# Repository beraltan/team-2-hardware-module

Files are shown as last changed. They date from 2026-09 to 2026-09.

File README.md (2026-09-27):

# Team 2 · Cardboard Camera

The battery is optional; the module can run on USB power. The outer shell is up to your group—get creative with its shape, materials and decoration!

## Assembly

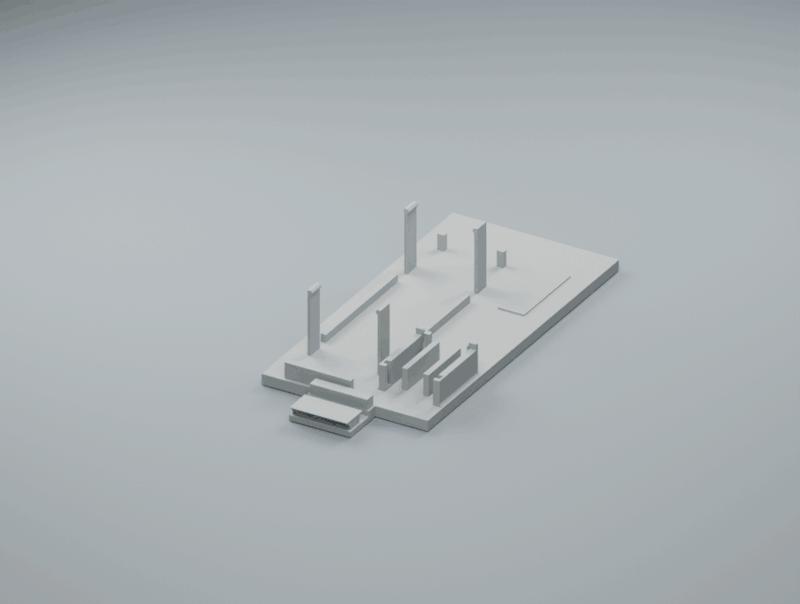
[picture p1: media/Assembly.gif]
Assembly video


[Watch / download video](media/Assembly.mp4)

## Print files

[Sled](design/cardboard-camera/Electronics%20Sled.stl) · [ESP lock](design/cardboard-camera/ESP%20Lock.stl) · [Radar holder](design/cardboard-camera/Radar%20Holder.stl) · [Front cover](design/cardboard-camera/Front%20Cover.stl)

[Assembly & wiring instructions](docs/BUILD_GUIDE.md)

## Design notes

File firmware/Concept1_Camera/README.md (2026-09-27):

# Radar camera firmware

Open Concept1_Camera.ino with both headers in this folder. Board: Seeed Studio XIAO ESP32-C3. Tested toolchain: Espressif Arduino core 3.3.11, ArduinoJson 6.21.5. Enable USB CDC on boot. CLI FQBN: esp32:esp32:XIAO_ESP32C3:CDCOnBoot=default.

The firmware reads LD2450 UART at 256000 8N1 and outputs USB JSON at 5 Hz. Wi-Fi credentials are entered through the local setup portal and stored on the device, not in source. The protected setup AP is named Team2-Camera-<device suffix>; obtain its generated password through the software facilitator's authenticated setup-info action over USB. Join the AP, then open http://192.168.4.1. OOCSI remains a separate opt-in setting.

Current directional LED firmware compiled successfully but still needs flashing and optical testing on the assembled device. Earlier versions were tested on USB/Wi-Fi; this does not verify the current guidance patterns. The LD2450_USB_Test sketch is a minimal diagnostic alternative.

See the repository README for wiring, build instructions and the paired software module.

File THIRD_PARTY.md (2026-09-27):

# Sources and rights

LD2450 manual: https://www.tinytronics.nl/product_files/006000_HLK-LD2450-Instruction-Manual.pdf

XIAO documentation: https://wiki.seeedstudio.com/XIAO_ESP32C3_Getting_Started/

Arduino-ESP32 and ArduinoJson are external dependencies, not bundled. OOCSI protocol implementation follows the official iddi/oocsi-python client. The included CAD is the Team 2 prototype with component clearance envelopes; these are not manufacturer-certified exact component models. No project-wide licence has been chosen by the team yet.

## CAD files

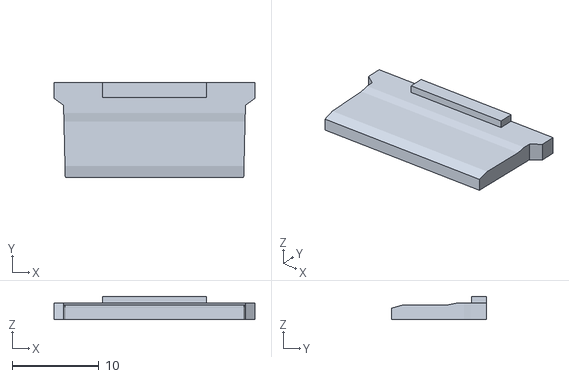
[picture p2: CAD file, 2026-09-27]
design/cardboard-camera/ESP Lock.stl
23.2 x 10.9 x 2.70

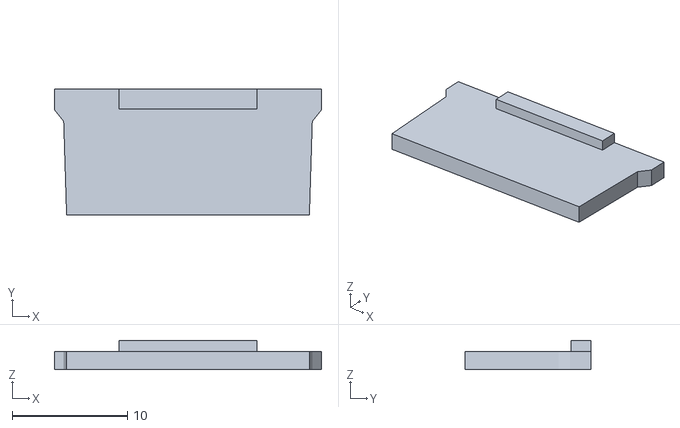
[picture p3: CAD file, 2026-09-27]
design/fit-checks/ESP End Stop Fit.stl
23.2 x 10.9 x 2.55

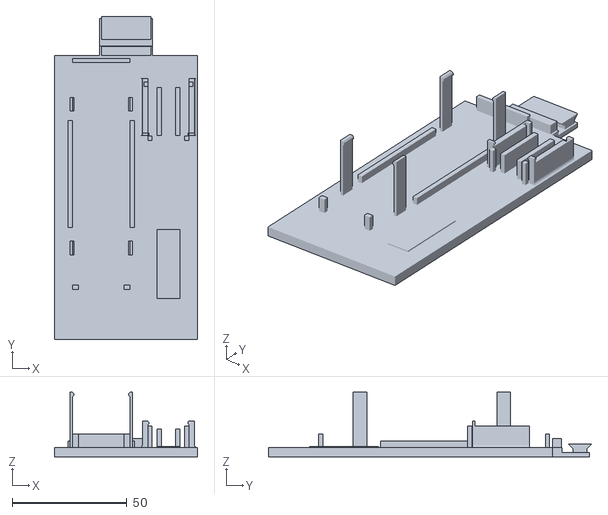
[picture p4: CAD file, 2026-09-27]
design/cardboard-camera/Electronics Sled.stl
62.4 x 141.0 x 28.2

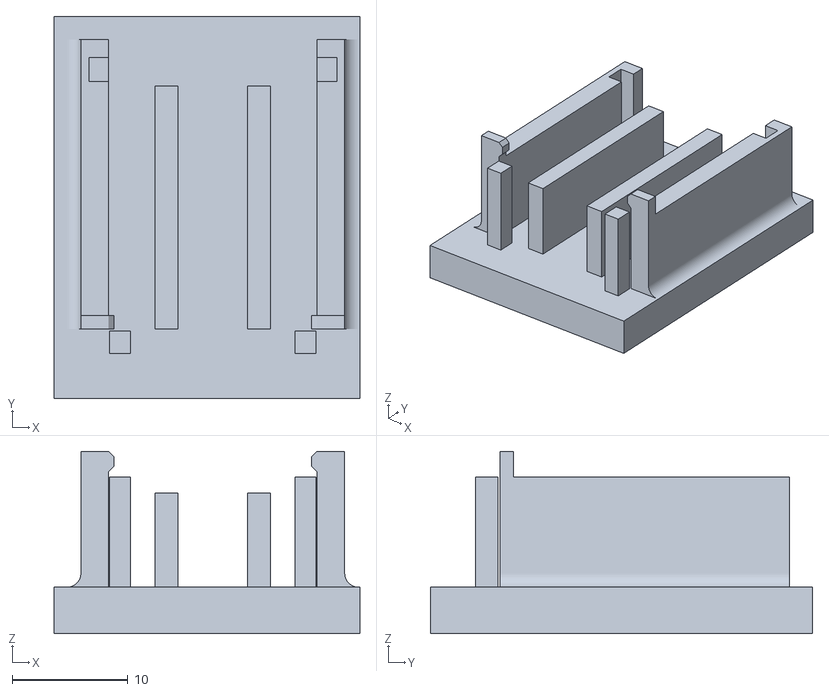
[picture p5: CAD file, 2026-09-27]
design/fit-checks/ESP Holder Fit Test.stl
26.4 x 33.0 x 15.7

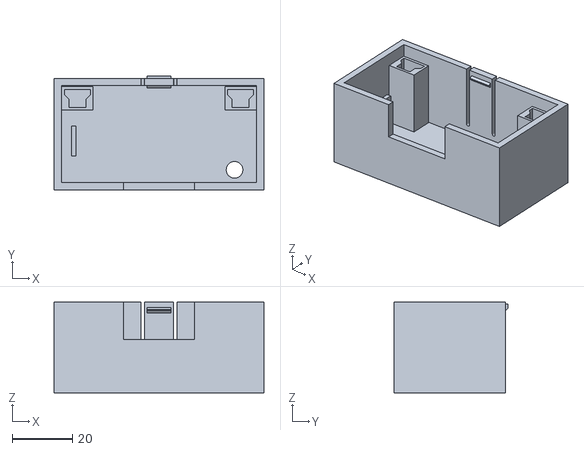
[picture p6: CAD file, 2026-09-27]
design/cardboard-camera/Front Cover.stl
69.5 x 37.6 x 30.0

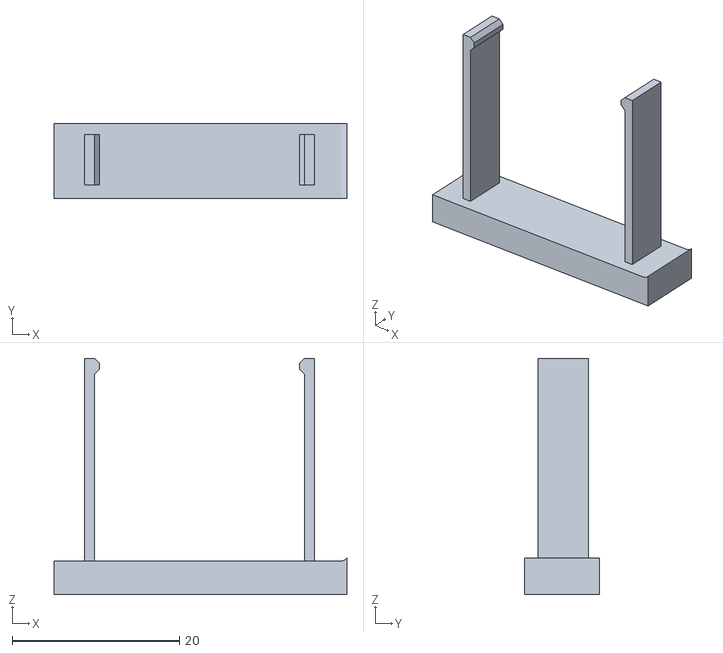
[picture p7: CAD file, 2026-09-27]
design/fit-checks/Battery Clip Fit Test.stl
35.0 x 9.00 x 28.2

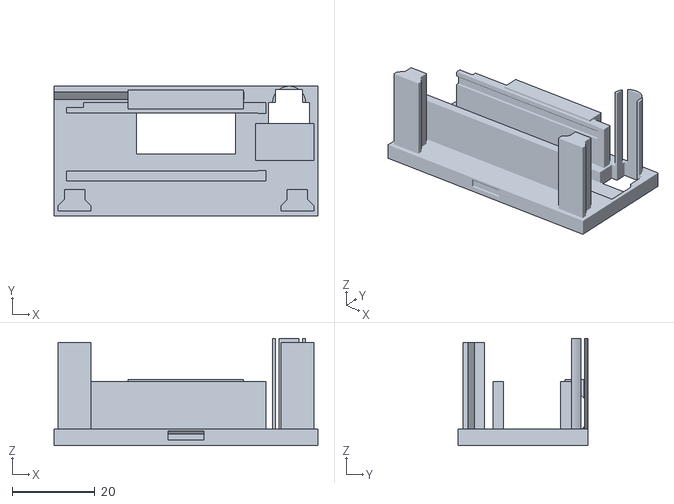
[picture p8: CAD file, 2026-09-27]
design/cardboard-camera/Radar Holder.stl
64.0 x 31.6 x 26.0

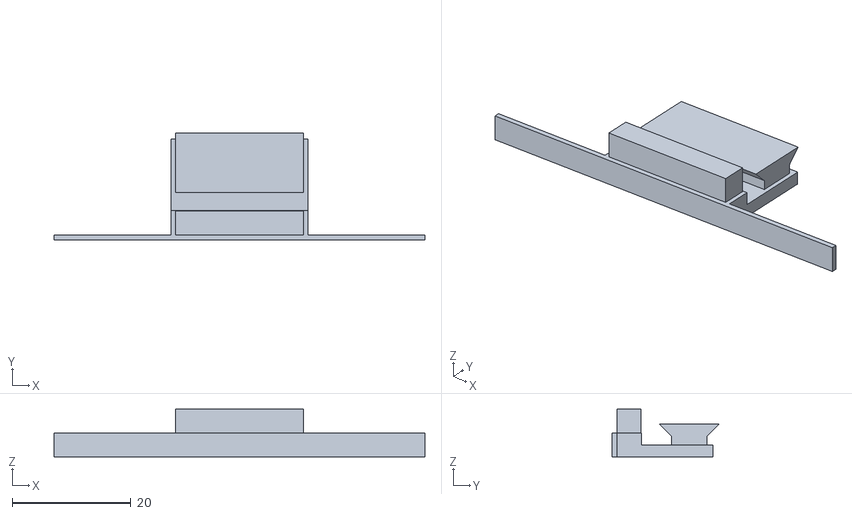
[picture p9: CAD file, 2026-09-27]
design/fit-checks/Dovetail Male Fit.stl
62.4 x 18.0 x 8.00

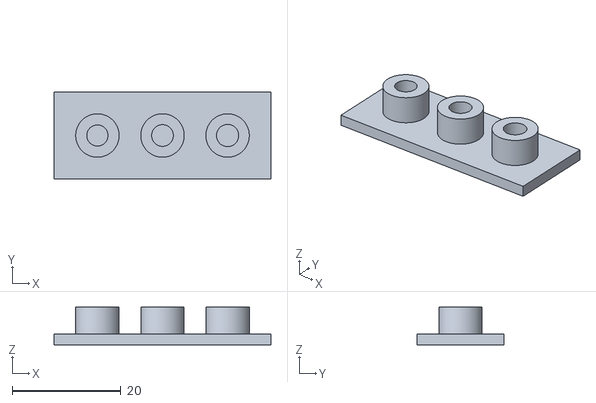
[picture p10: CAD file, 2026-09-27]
design/fit-checks/M3 Insert Fit.stl
40.0 x 16.0 x 7.00

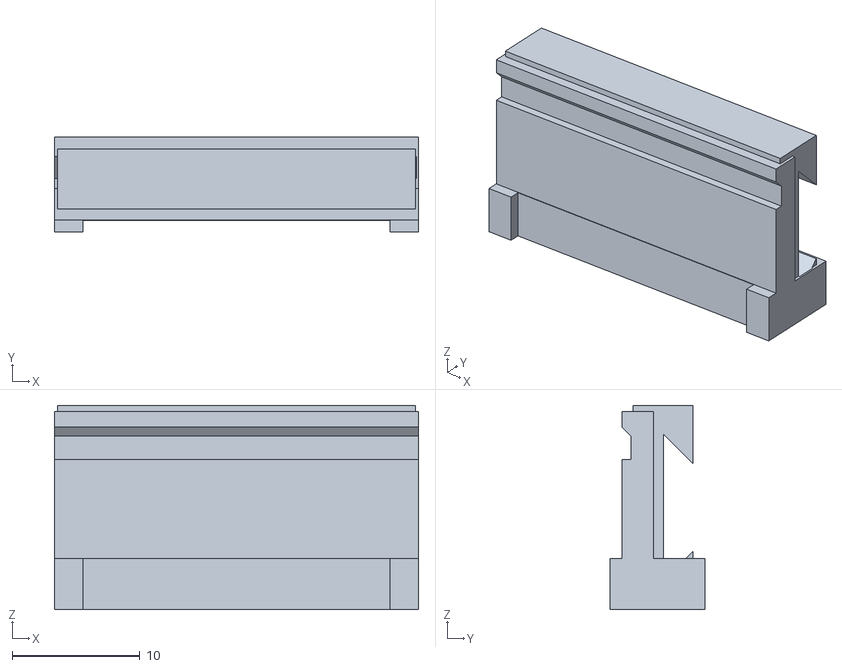
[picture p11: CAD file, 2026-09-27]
design/fit-checks/Dovetail Female Fit.stl
28.5 x 7.47 x 16.0

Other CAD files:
design/fit-checks/ESP Well Fit.stl

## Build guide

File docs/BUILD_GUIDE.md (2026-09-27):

# Team 2 — Hardware module: radar camera

Position-sensing camera prop for the Bank Heist connected experience. An LD2450 radar and XIAO ESP32-C3 send player positions; an RGB LED receives navigator guidance. The visible enclosure is cardboard, with printed internal mounts and a front head.

**Software module:** https://github.com/beraltan/team-2-software-module

The battery and power-bank assembly are optional: you can power the module through the XIAO's USB-C port instead. Skip the battery fit test and installation if using external USB power.

The outer shell is entirely up to your group. Be creative with its shape, materials, colours and decoration; the cardboard camera in the video is one example. Keep the radar's sensing area, LED, cables and power connection clear when designing your shell.

## Contents

- [Cardboard camera STL files](../design/cardboard-camera): Electronics Sled, Radar Holder, ESP Lock and Front Cover.
- Print the [ESP holder fit test](../design/fit-checks/ESP%20Holder%20Fit%20Test.stl) with the [ESP lock](../design/cardboard-camera/ESP%20Lock.stl), and the [battery clip fit test](../design/fit-checks/Battery%20Clip%20Fit%20Test.stl) before the complete sled.
- [Camera firmware](../firmware/Concept1_Camera/README.md): UART sensing, USB JSON, Wi-Fi setup and optional OOCSI.
- firmware/LD2450_USB_Test: minimal radar wiring test.
- [Shared interface](INTERFACE.md).

## Parts and wiring

| Part | Quantity / connection |
| --- | --- |
| HLK-LD2450 | 1; 5V and GND; TX to XIAO D7, RX to D6 |
| Seeed XIAO ESP32-C3 | 1; headers upward in the printed well |
| Common-cathode 5 mm RGB LED | 1; R→D0, G→D1, B→D2, cathode→GND |
| LED resistors | One per colour; select for the purchased LED forward voltage/current at 3.3V |
| Optional USB power-bank case and battery | 96.65 × 24.91 × 22.23 mm, with purchased compatible cell; omit for external USB power |
| Printed joints | Screw-free head-to-sled dovetail and sliding front cover with release detent |
| Shell materials | Your group's choice; cardboard is used in the example |

Power down before wiring; verify the actual LED lead order. Do not connect two independent 5V sources together. Use the assembled power-bank electronics for battery charging; do not connect the bare cell to the XIAO 5V pin.

## Assemble and run

1. Print the fit-check STLs, inspect sliced layers and check the purchased parts.
2. Import the four production STLs into Bambu Studio in millimetres, keeping their supplied print orientations. Use the sled underside, holder backplate, end stop flat face and cover front face on the bed. PLA is suitable for initial indoor fit checks. Slice for your printer and filament.
3. Slide the XIAO into its well with the head detached and headers upward, then lower the ESP lock vertically into its slot. If using a battery, seat the power bank between its retaining clips and end stops. Slide the head onto the transverse dovetail, then insert the radar from the open end of its PCB channels toward the fixed stop. Fit the LED and route insulated leads clear of joints.
4. Slide the front cover onto its two guides until the roof detent seats. The rear notch captures the head-to-sled dovetail. Lift the roof release tab gently before withdrawing the cover. Fit your group's shell; preserve USB access and, if fitted, charging-port access.
5. Install the Arduino dependencies and upload the camera sketch with USB CDC enabled. Close serial monitors before starting the software module.
6. Start the paired software module with the correct serial port. Verify coordinates, LED behaviour and tracking through the finished cover before a game.

## CAD and verification status

Design downloads are STL files only. Use all four production parts together. The head slides sideways onto the sled dovetail; the front cover captures the joint and prevents sideways release. Remove the cover before sliding the head off.

The current revision has four connected, watertight print meshes. Sampled CAD travel checks found no rigid interference for the ESP lock, head dovetail or cover guides; the flexible cover detent is evaluated separately. The print orientation audit found no sampled faces steeper than 45 degrees above the bed. These checks do not establish physical strength, spring fatigue, RF transmission or printed fit. Test the small coupons first, particularly the ESP lock's final seating travel. The 4 mm radar cover needs testing with the actual filament. The group assembled an earlier physical prototype; the revised fits are not yet physically validated.

Team 2: Anouk Kramer, Alp Altaner, Berk Eraltan Sönmezgil, Sebastiaan Schenk.

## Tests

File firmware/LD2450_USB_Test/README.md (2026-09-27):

# One-radar USB bench test

Unplug USB while wiring. Connect by the radar's printed signal labels, not assumed wire colours or connector left-to-right order.

| LD2450 | XIAO ESP32-C3 |
| --- | --- |
| 5V | 5V |
| GND | GND |
| TX | D7 / GPIO20 (RX) |
| RX | D6 / GPIO21 (TX) |

Connect the XIAO to the PC with a USB data cable. Do not connect the battery/power-bank supply for this bench test. The radar requires 5 V power and a supply capable of more than 200 mA for the radar itself; its UART uses 3.3 V logic, compatible with the XIAO. Never feed 5 V into an ESP GPIO or power the radar from 3V3.

Open `LD2450_USB_Test.ino` in Arduino IDE. Install **esp32 by Espressif Systems** in Boards Manager if absent. Select **XIAO_ESP32C3**, set **USB CDC On Boot = Enabled**, select its COM port and upload. Open Serial Monitor at **115200**. The independent radar UART runs at **256000, 8N1**. No extra library is required.

Walk in front of the radar with its antenna face pointing into the room. Every half-second the monitor shows the latest X/Y coordinates (mm), speed (cm/s) and distance-gate resolution (mm) for up to three target slots. The resolution field is not an accuracy claim. Target slot numbers are not persistent person identities. This passive test sends no configuration commands and assumes the radar's default baud rate.

`Connected; no targets` means valid radar frames are arriving. `NO FRESH RADAR DATA` means the UART link is not providing valid recent frames; check power, common ground, crossed TX/RX, selected pins and any previously changed radar baud rate. If the monitor is entirely blank, check USB CDC, the COM port and the USB data cable, then press RESET. If upload fails, hold BOOT while connecting USB, release it, select the new port and retry.

Protocol: 30-byte frames with `AA FF 03 00` header and `55 CC` trailer. Three 8-byte target records; X, Y and speed use little-endian magnitude with bit 15 indicating positive. An all-zero target record is empty. The protocol has no checksum; the sketch checks framing and resynchronizes after corruption, but cannot detect every payload error. Host timestamps are reception times, not measured sensor latency.

Sources: [Hi-Link manual, pages 9–13](https://www.tinytronics.nl/product_files/006000_HLK-LD2450-Instruction-Manual.pdf), [Seeed pinout](https://wiki.seeedstudio.com/XIAO_ESP32C3_Getting_Started/).

Status: compiled and uploaded to the connected XIAO ESP32-C3 on COM4 on 2026-09-16 using Arduino CLI and Espressif core 3.3.11, with USB CDC enabled. Flash verification passed. A USB serial capture confirmed live LD2450 target frames at approximately 11 frames/s, with changing X/Y positions and speed. This verifies basic communication and decoding, not calibrated position accuracy or latency. The serial port was closed after capture; the board continues running the test.

Evidence: `../../logs/ld2450_compile.log`, `../../logs/ld2450_upload.log`, and `../../logs/ld2450_serial_test.log`. Compiled size: 285,908 bytes flash and 13,472 bytes static RAM.

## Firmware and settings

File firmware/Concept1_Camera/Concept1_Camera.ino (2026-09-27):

// Team 2 Concept 1. LD2450 -> D7/GPIO20 RX, D6/GPIO21 TX, 5V, GND.
// Common-cathode RGB: D0/GPIO2 red, D1/GPIO3 green, D2/GPIO4 blue.
// Each LED anode needs its own current-limiting resistor. LED is optional for USB testing.
// OOCSI TCP wire protocol follows the official iddi/oocsi-python client (MIT).
#include <Arduino.h>
#include <ArduinoJson.h>
#include <WiFi.h>
#include <Preferences.h>

struct Target { int x, y, speed, resolution; bool present; };
struct Reading { Target targets[3]; bool valid; int x,y,count; uint32_t seq,frame,ms; };
portMUX_TYPE mutex = portMUX_INITIALIZER_UNLOCKED;
Reading shared = {};
char guideState[12]="stop";
char gameState[12] = "idle";
char gameSession[48] = "";
uint32_t gameBeat=0, heartbeatAt=0, guideAt=0;
bool haveHeartbeat=false, netEnabled=false, netConnected=false;
char wifiSSID[33]="", wifiPassword[65]="", teamChannel[100]="";
char bootID[16];
uint8_t frameBuffer[30]; size_t used=0;
Target latest[3] = {};
uint32_t frames=0, lastFrameAt=0, sequence=0;
String serialLine;
Preferences prefs;
#include "wifi_setup.h"

int word(const uint8_t*p) { return p[0] | (p[1]<<8); }
int signedValue(const uint8_t*p) { int v=word(p); return (v&0x8000)?(v&0x7fff):-(v&0x7fff); }

void heartbeat(JsonVariantConst d) {
  if(!d["toktik_beat"].is<uint32_t>() || !d["toktik_state"].is<const char*>()) return;
  const char* s=d["toktik_state"]; const char* session=d["toktik_session"] | "";
  if(!*session || strlen(session)>=sizeof(gameSession)) return;
  if(strcmp(s,"idle")&&strcmp(s,"running")&&strcmp(s,"won")&&strcmp(s,"lost")&&strcmp(s,"fault")) return;
  uint32_t beat=d["toktik_beat"];
  portENTER_CRITICAL(&mutex);
  if(strcmp(session,gameSession)!=0 || !haveHeartbeat || beat>gameBeat) {
    strlcpy(gameSession,session,sizeof(gameSession)); strlcpy(gameState,s,sizeof(gameState));
    const char* guide=d["toktik_guide"] | "stop";
    if(strcmp(guide,"left")&&strcmp(guide,"right")&&strcmp(guide,"forward")&&strcmp(guide,"back")) guide="stop";
    if(strcmp(guideState,guide))guideAt=millis();
    strlcpy(guideState,guide,sizeof(guideState));
    gameBeat=beat; heartbeatAt=millis(); haveHeartbeat=true;
  }
  portEXIT_CRITICAL(&mutex);
}

void serialCommand() {
  while(Serial.available()) {
    char c=Serial.read();
    if(c=='\n') {
      StaticJsonDocument<2048> d;
      if(!deserializeJson(d,serialLine)) {
        const char* command=d["command"] | "";
        if(!strcmp(command,"setup_info")) {
          StaticJsonDocument<256> info;info["type"]="setup";info["ssid"]=setupSSID;info["password"]=setupPassword;info["url"]="http://192.168.4.1";serializeJson(info,Serial);Serial.println();
        }
        if(!strcmp(command,"heartbeat")) heartbeat(d.as<JsonVariantConst>());
        if(!strcmp(command,"wifi_config")) {
          const char* ssid=d["ssid"] | ""; const char* password=d["password"] | "";
          const char* channel=d["channel"] | "";
          if(strlen(ssid)>0 && strlen(ssid)<=32 && strlen(password)<=64 && strlen(channel)>0 && strlen(channel)<100 && !strchr(channel,' ') && !strchr(channel,'\n')) {
            prefs.putString("ssid",ssid); prefs.putString("password",password); prefs.putString("channel",channel);
            prefs.putBool("enabled",d["enabled"] | false);
            prefs.putBool("wifi_on",true);
            Serial.println("{\"type\":\"config\",\"saved\":true,\"restarting\":true}"); Serial.flush(); delay(100); ESP.restart();
          }
        }
        if(!strcmp(command,"wifi_disable")) { prefs.putBool("enabled",false); prefs.putBool("wifi_on",false); Serial.println("{\"type\":\"config\",\"wifi_disabled\":true}"); Serial.flush(); delay(100); ESP.restart(); }
      }
      serialLine="";
    } else if(c!='\r') { if(serialLine.length()<2047) serialLine+=c; else serialLine=""; }
  }
}

void radarRead() {
  while(Serial1.available()) {
    uint8_t b=Serial1.read();
    if(used==30) { memmove(frameBuffer,frameBuffer+1,29); used=29; }
    frameBuffer[used++]=b;
    if(used==30 && frameBuffer[0]==0xAA && frameBuffer[1]==0xFF && frameBuffer[2]==3 && frameBuffer[3]==0 && frameBuffer[28]==0x55 && frameBuffer[29]==0xCC) {
      for(int i=0;i<3;i++) { const uint8_t*p=frameBuffer+4+i*8; bool present=false; for(int j=0;j<8;j++) present|=p[j]!=0;
        latest[i]={signedValue(p),signedValue(p+2),signedValue(p+4),word(p+6),present}; }
      frames++; lastFrameAt=millis(); used=0;
    }
  }
}

void payload(JsonDocument& d, const Reading&r) {
  d["guidance_supported"]=true;
  d["type"]="radar"; d["radar_boot"]=bootID; d["radar_seq"]=r.seq; d["radar_frame"]=r.frame;
  d["radar_device_ms"]=r.ms; d["radar_valid"]=r.valid; d["radar_x_mm"]=r.x; d["radar_y_mm"]=r.y; d["radar_target_count"]=r.count;
}

void networkTask(void*) {
  // Network timeouts run on their own task so UART reading and LED deadlines continue.
  beginSetupPortal();
  WiFiClient client; client.setTimeout(1000);
  String input; uint32_t lastTry=0, sentSeq=0, lastByte=millis(); bool greeted=false;
  String handle=String("team2_camera_")+bootID;
  while(true) {
    serviceSetupPortal();
    if(!netEnabled){netConnected=false;client.stop();greeted=false;vTaskDelay(pdMS_TO_TICKS(10));continue;}
    if(WiFi.status()!=WL_CONNECTED) { netConnected=false; client.stop(); greeted=false; if(millis()-lastTry>10000){lastTry=millis();WiFi.reconnect();} }
    else if(!client.connected()) {
      netConnected=false; greeted=false; input="";
      if(millis()-lastTry>3000) { lastTry=millis(); if(client.connect("oocsi.id.tue.nl",4444,1000)) {client.println(handle+"(JSON)");lastByte=millis();} }
    } else {
      while(client.available()) {
        char c=client.read(); lastByte=millis();
        if(c=='\n') {
          if(input.startsWith("ping")||input.startsWith(".")) client.println(".");
          else if(input.startsWith("{")) {
            StaticJsonDocument<2048> d;
            if(!deserializeJson(d,input)) {
              if(!greeted) {greeted=true;netConnected=true;client.println(String("subscribe ")+teamChannel);}
              else if(d["recipient"]==teamChannel) heartbeat(d.as<JsonVariantConst>());
            }
          } else if(input.startsWith("error")) client.stop();
          input="";
        } else if(c!='\r') { if(input.length()<2047) input+=c; else {input="";client.stop();} }
      }
      if(!greeted && millis()-lastByte>3000) client.stop();
      if(millis()-lastByte>30000) client.stop();
      Reading r; portENTER_CRITICAL(&mutex); r=shared; portEXIT_CRITICAL(&mutex);
      if(greeted && r.seq!=sentSeq) {
        StaticJsonDocument<768> d; payload(d,r); String out; serializeJson(d,out);
        client.println(String("sendraw ")+teamChannel+" "+out); sentSeq=r.seq;
      }
    }
    vTaskDelay(pdMS_TO_TICKS(10));
  }
}

void setup() {
  Serial.begin(115200); Serial1.setRxBufferSize(2048); Serial1.begin(256000,SERIAL_8N1,20,21);
  pinMode(2,OUTPUT);pinMode(3,OUTPUT);pinMode(4,OUTPUT);
  digitalWrite(2,LOW);digitalWrite(3,LOW);digitalWrite(4,LOW);
  snprintf(bootID,sizeof(bootID),"%08lx",(unsigned long)esp_random());
  prefs.begin("team2camera",false);
  strlcpy(wifiSSID,prefs.getString("ssid","").c_str(),sizeof(wifiSSID));
  strlcpy(wifiPassword,prefs.getString("password","").c_str(),sizeof(wifiPassword));
  strlcpy(teamChannel,prefs.getString("channel","").c_str(),sizeof(teamChannel));
  netEnabled=prefs.getBool("enabled",false)&&strlen(wifiSSID)&&strlen(teamChannel);
  xTaskCreate(networkTask,"oocsi",8192,nullptr,1,nullptr);
}

void loop() {
  radarRead(); serialCommand(); uint32_t now=millis(); static uint32_t lastPublish=0;
  bool valid=frames && now-lastFrameAt<400; int count=0,x=0,y=0;
  for(auto&t:latest) if(valid&&t.present&&t.x>=-1500&&t.x<=1500&&t.y>=1500&&t.y<=4500) {count++;x=t.x;y=t.y;}
  valid=valid&&count==1;
  char state[12],guide[12]; uint32_t age,cueAge; bool heard;
  portENTER_CRITICAL(&mutex); strlcpy(state,gameState,sizeof(state));strlcpy(guide,guideState,sizeof(guide)); age=now-heartbeatAt;cueAge=now-guideAt;heard=haveHeartbeat; portEXIT_CRITICAL(&mutex);
  bool running=!strcmp(state,"running"), fault=!strcmp(state,"fault");
  bool green=running&&valid&&heard&&age<2000;
  bool amber=(running&&!green)||fault;
  bool flash=amber&&((now/300)%2==0);
  int pulses=!strcmp(guide,"left")?1:!strcmp(guide,"right")?2:!strcmp(guide,"forward")?3:!strcmp(guide,"back")?4:0;
  // Four possible pulse counts, followed by a clear pause. Colour reinforces the axis.
  int phase=cueAge%2000; bool on=phase<pulses*300 && phase%300<150;
  bool blue=green&&pulses>0&&pulses<=2&&on;
  bool forwardGreen=green&&pulses>=3&&on;
  digitalWrite(2,(flash||(green&&pulses==0))?HIGH:LOW);digitalWrite(3,(flash||forwardGreen)?HIGH:LOW);digitalWrite(4,blue?HIGH:LOW);
  if(now-lastPublish>=200) {
    lastPublish=now; Reading r={}; memcpy(r.targets,latest,sizeof(latest));r.valid=valid;r.x=valid?x:0;r.y=valid?y:0;r.count=count;r.seq=++sequence;r.frame=frames;r.ms=now;
    portENTER_CRITICAL(&mutex);shared=r;portEXIT_CRITICAL(&mutex);
    StaticJsonDocument<2048> d;payload(d,r);d["wifi_enabled"]=stationAllowed&&strlen(wifiSSID);d["oocsi_enabled"]=netEnabled;d["oocsi_connected"]=netConnected;d["wifi_connected"]=WiFi.status()==WL_CONNECTED;d["setup_ssid"]=setupSSID;
    d["wifi_ip"]=WiFi.localIP().toString();d["wifi_gateway"]=WiFi.gatewayIP().toString();d["wifi_rssi_dbm"]=WiFi.RSSI();d["portal_age_ms"]=now-portalServicedAt;
    d["led"]=green?guide:amber?"fault-amber":"off";d["guidance_supported"]=true; d["heartbeat_age_ms"]=heard?age:0;
    JsonArray a=d.createNestedArray("targets");
    if(frames&&now-lastFrameAt<400) for(int i=0;i<3;i++) if(latest[i].present){JsonObject t=a.createNestedObject();t["id"]=i+1;t["x"]=latest[i].x;t["y"]=latest[i].y;t["speed"]=latest[i].speed;t["resolution"]=latest[i].resolution;}
    // USB CDC can disappear without blocking sensor/LED work indefinitely.
    if(Serial && Serial.availableForWrite()>0){serializeJson(d,Serial);Serial.println();}
  }
  delay(1);
}

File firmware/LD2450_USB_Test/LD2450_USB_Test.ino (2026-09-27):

// Seeed Studio XIAO ESP32-C3 + HLK-LD2450. No extra libraries.
// Arduino board: XIAO_ESP32C3. USB CDC On Boot: Enabled.
// LD2450 5V -> XIAO 5V, GND -> GND, TX -> D7/GPIO20, RX -> D6/GPIO21.
// Power from the PC's USB port. The radar needs 5V power, not 3V3.
#include <Arduino.h>
#include <string.h>

constexpr int RADAR_RX = 20;
constexpr int RADAR_TX = 21;
constexpr uint32_t RADAR_BAUD = 256000;
uint8_t windowBytes[30] = {};
uint8_t latest[30] = {};
size_t used = 0;
uint32_t frames = 0, bytesReceived = 0, lastFrameMs = 0, lastPrintMs = 0;

uint16_t readLE(const uint8_t *p) {
  return uint16_t(p[0]) | (uint16_t(p[1]) << 8);
}

int decodeSigned(const uint8_t *p) {
  const uint16_t raw = readLE(p);
  const int magnitude = raw & 0x7FFF;
  // LD2450 uses bit 15 = POSITIVE, not ordinary two's-complement int16.
  return (raw & 0x8000) ? magnitude : -magnitude;
}

void setup() {
  Serial.begin(115200);
  Serial1.setRxBufferSize(1024);
  Serial1.begin(RADAR_BAUD, SERIAL_8N1, RADAR_RX, RADAR_TX);
  delay(1500);
  Serial.println("LD2450 position test: X/Y in mm; speed in cm/s.");
  Serial.println("Waiting for radar at 256000 baud on D7/GPIO20...");
}

void loop() {
  while (Serial1.available()) {
    const uint8_t b = uint8_t(Serial1.read());
    ++bytesReceived;
    if (used == sizeof(windowBytes)) {
      memmove(windowBytes, windowBytes + 1, sizeof(windowBytes) - 1);
      --used;
    }
    windowBytes[used++] = b;
    // Sliding window resynchronizes after noise, partial packets or dropped bytes.
    if (used == 30 && windowBytes[0] == 0xAA && windowBytes[1] == 0xFF &&
        windowBytes[2] == 0x03 && windowBytes[3] == 0x00 &&
        windowBytes[28] == 0x55 && windowBytes[29] == 0xCC) {
      memcpy(latest, windowBytes, sizeof(latest));
      ++frames;
      lastFrameMs = millis();
      used = 0;
    }
  }

  const uint32_t now = millis();
  if (now - lastPrintMs < 500) return;
  lastPrintMs = now;
  if (!frames || now - lastFrameMs > 2000) {
    Serial.printf("NO FRESH RADAR DATA | bytes=%lu frames=%lu | check 5V, GND, TX->D7 and baud\n",
                  (unsigned long)bytesReceived, (unsigned long)frames);
    return;
  }

  Serial.printf("t=%lu ms | frame=%lu | ", (unsigned long)now, (unsigned long)frames);
  int count = 0;
  for (int i = 0; i < 3; ++i) {
    const uint8_t *p = latest + 4 + i * 8;
    bool present = false;
    for (int j = 0; j < 8; ++j) present |= p[j] != 0;
    if (!present) continue;
    ++count;
    Serial.printf("T%d: x=%d y=%d speed=%d resolution=%u | ",
                  i + 1, decodeSigned(p), decodeSigned(p + 2),
                  decodeSigned(p + 4), unsigned(readLE(p + 6)));
  }
  if (!count) Serial.print("Connected; no targets");
  Serial.println();
}

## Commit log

2026-09-27 Team 2 cardboard camera: print files, assembly video and firmware
    [Battery Clip Fit Test.stl, Dovetail Female Fit.stl, Dovetail Male Fit.stl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]
2026-10-01 Publish tighter radar holder and camera firmware with Mac setup
2026-10-28 Publish complete heist firmware and illustrated wiring handover
2026-10-28 Document camera verification and clarify archived laser firmware
